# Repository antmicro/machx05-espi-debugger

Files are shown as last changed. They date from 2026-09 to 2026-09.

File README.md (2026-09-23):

# MachXO5 eSPI Debugger

Copyright (c) 2026 [Antmicro](https://www.antmicro.com)

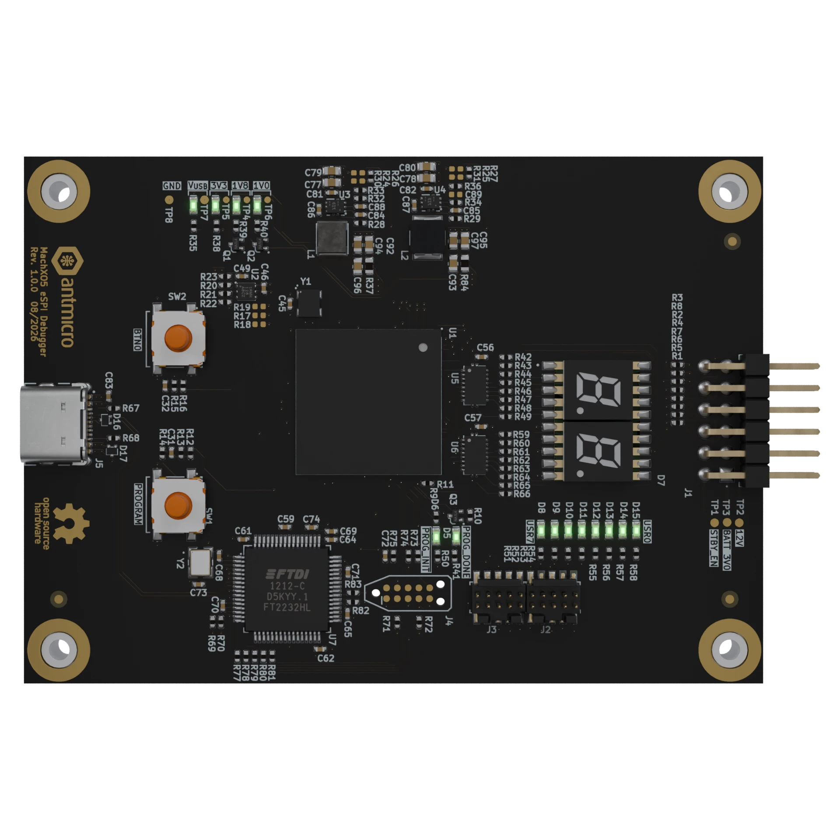
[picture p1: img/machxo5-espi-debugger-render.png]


## Overview

This project contains open hardware design files for an FPGA-based debug board built around the Lattice MachXO5-NX FPGA.
The board is designed to aid the process of development, bring-up and integration of eSPI-based connections to Data Center Secure Control Modules (DC-SCMs).
It provides USB-accessible UART and JTAG interfaces and a Port 80 status display, enabling development, testing and debugging of eSPI communication before integration into a target server platform.
This project includes only PCB design files - as dedicated bitstream needs to be generated for the on-board Lattice FPGA in order to make it work.
The PCB design files were prepared in KiCad 10.x.

## Key features

* Lattice [MachXO5-NX LFMXO5-25-7BBG400C](https://www.latticesemi.com/en/Products/FPGAandCPLD/MachXO5-NX) FPGA
* Generic 0.1 inch pinhead connector for interfacing with HPM subsystem
* USB-C port with FTDI FT2232H USB interface bridge
* UART and JTAG interfaces accessible from the USB interface bridge
* Port 80 status display with LED indicators
* 125 MHz on-board clock source
* 62 x 87 mm (2.44 x 3.42 inch) PCB outline

## Project structure

The main directory contains KiCad PCB project files, the LICENSE, and this README, and the img directory contains graphics for this README.

## License

This project is licensed under the [Apache-2.0](LICENSE) license.

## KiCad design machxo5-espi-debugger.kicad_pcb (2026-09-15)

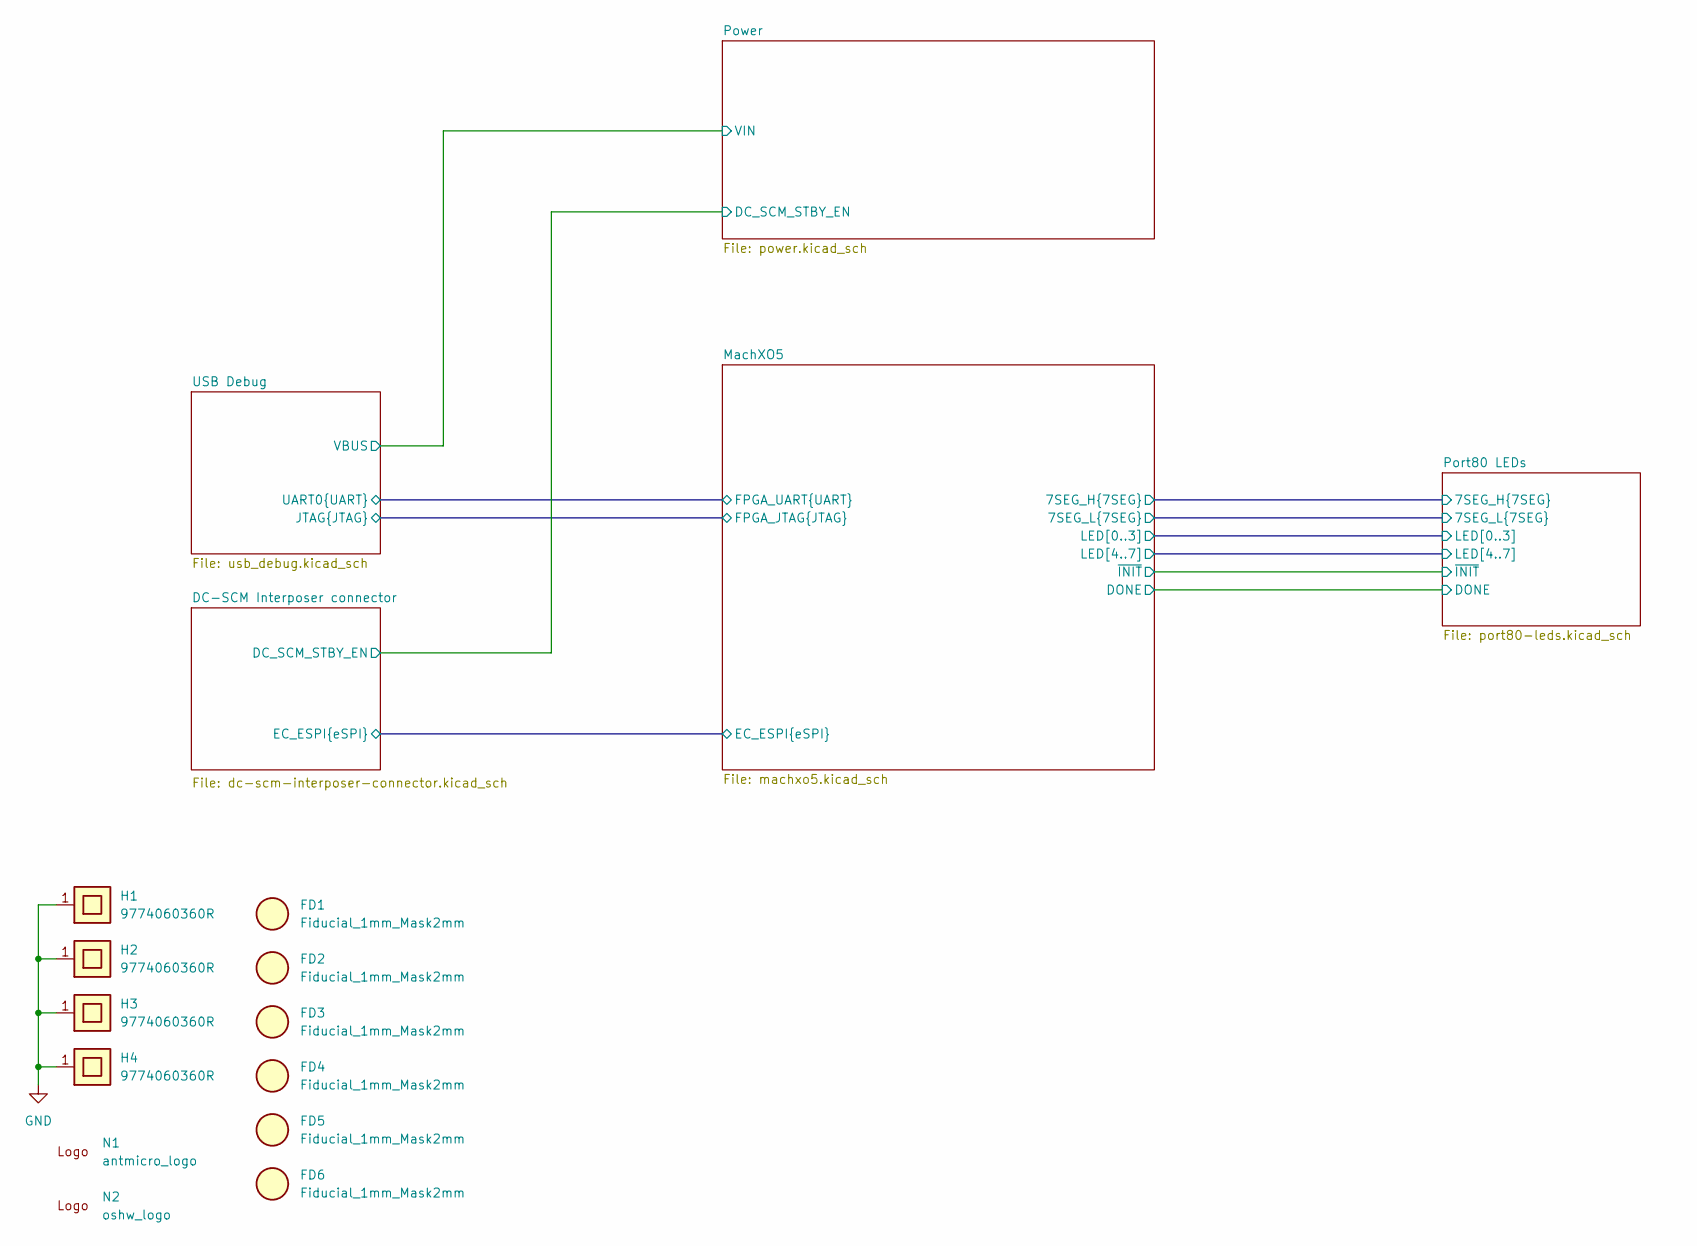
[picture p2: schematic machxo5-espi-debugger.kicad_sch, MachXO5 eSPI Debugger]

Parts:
FD1, FD2, FD3, FD4, FD5, FD6: Fiducial_1mm_Mask2mm
H1, H2, H3, H4: Spacer_Drill4.4mm_H6mm_9774060360R; MPN 9774060360R
N1: antmicro_logo; antmicro-logo_scaled_12mm
N2: oshw_logo; oshw-logo

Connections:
GND: H1.1, H2.1, H3.1, H4.1; also elsewhere on the board

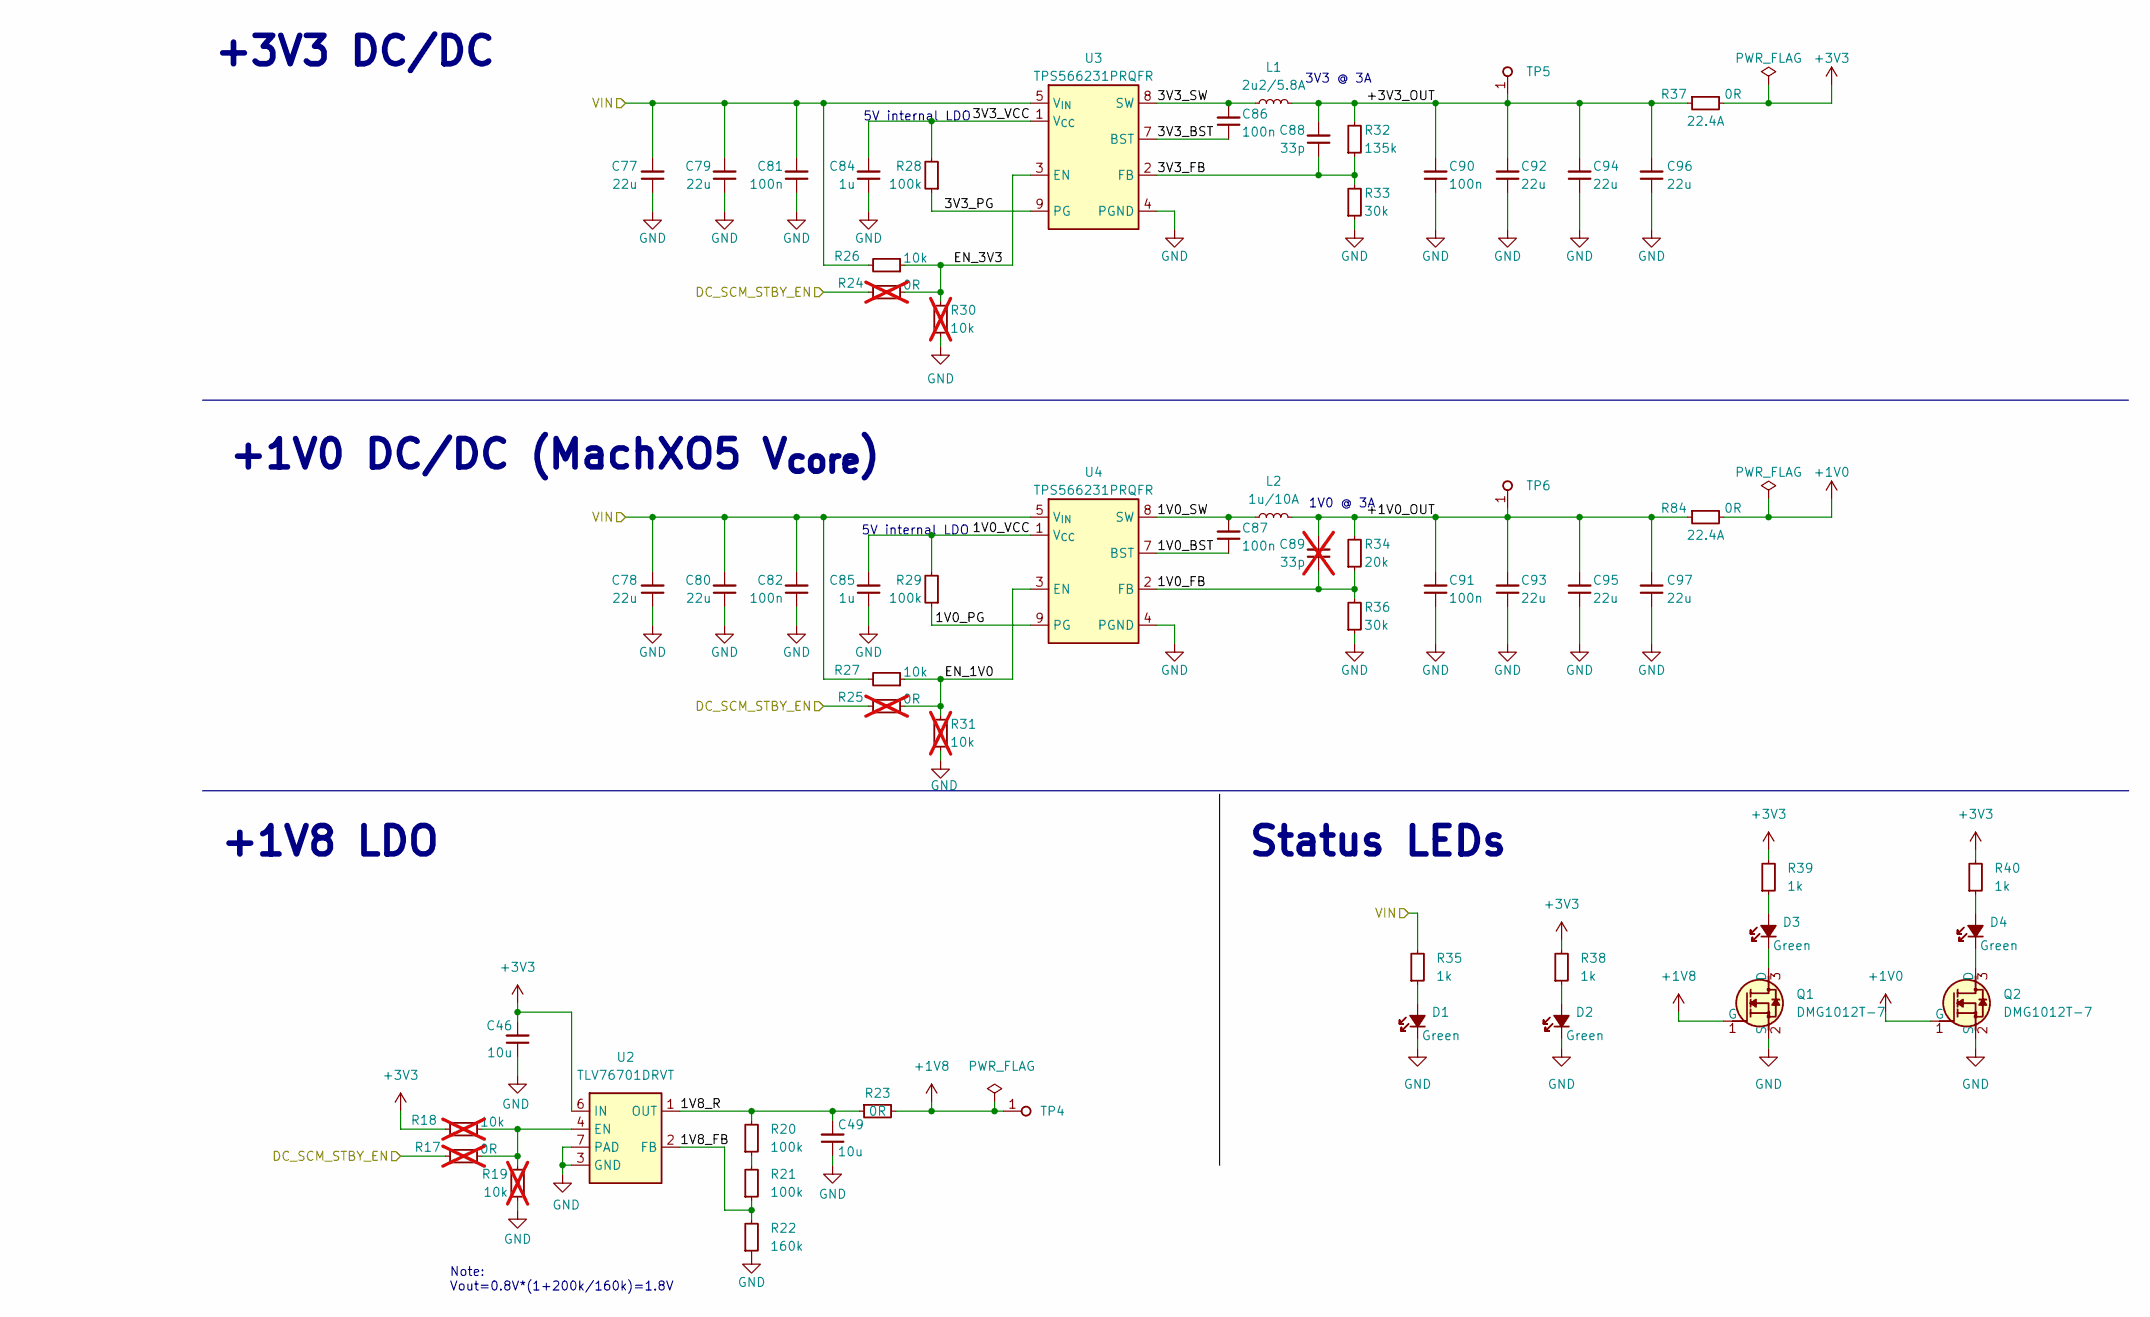
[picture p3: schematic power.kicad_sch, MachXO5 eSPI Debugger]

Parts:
C46, C49: C_10u_10V_0402; C_0402_1005Metric; Voltage 10V; MPN GRM155R61A106ME11D
C77, C78, C79, C80, C92, C93, C94, C95, C96, C97: C_22u_16V_0603; C_0603_1608Metric_EIA; Voltage 16V; MPN CL10A226MO7JZNC
C81, C82, C86, C87, C90, C91: C_100n_0402; C_0402_1005Metric; Voltage 50V; MPN GRM155R61H104KE14D
C84, C85: C_1u_25V_0402; C_0402_1005Metric; Voltage 25V; MPN GRM155R61E105KE11J
C88: C_33p_0402; C_0402_1005Metric; MPN 04025A330FAT2A
C89: C_33p_0402; C_0402_1005Metric; MPN 04025A330FAT2A; not fitted
D1, D2, D3, D4: LED_G_0603_LTST-C190GKT; LED_0603_1608Metric_G; MPN LTST-C190GKT
L1: L_2u2_5.8A_WE-PMFI-35329222; L_WE-PMFI-353220; MPN 74479335329222
L2: L_1u_10A_Bourns-SRP4021HMT; L_Bourns-SRP4021HMT; MPN SRP4021HMT-1R0M
Q1, Q2: DMG1012T-7; SOT-523; MPN DMG1012T-7
R17, R24, R25: R_0R_0402; R_0402_1005Metric; MPN ERJ2GE0R00X; not fitted
R18, R19, R30, R31: R_10k_0402; R_0402_1005Metric; Tolerance 1%; MPN CR0402-FX-1002GLF; not fitted
R20, R21, R28, R29: R_100k_0402; R_0402_1005Metric; Tolerance 1%; MPN CR0402-FX-1003GLF
R22: R_160k_0402; R_0402_1005Metric; Tolerance 1%; MPN CR0402-FX-1603GLF
R23: R_0R_0402; R_0402_1005Metric; MPN ERJ2GE0R00X
R26, R27: R_10k_0402; R_0402_1005Metric; Tolerance 1%; MPN CR0402-FX-1002GLF
R32: R_135k_0402; R_0402_1005Metric; Tolerance 0.1%; MPN RT0805BRD07135KL
R33, R36: R_30k_0402; R_0402_1005Metric; Tolerance 1%; MPN CR0402-FX-3002GLF
R34: R_20k_0402; R_0402_1005Metric; Tolerance 1%; MPN CR0402-FX-2002GLF
R35, R38, R39, R40: R_1k_0402; R_0402_1005Metric; Tolerance 1%; MPN CR0402-FX-1001GLF
R37, R84: R_0R_22.4A_0603; R_0603_1608Metric; Tolerance template_tolerance; MPN PMR03EZPJ000
TP4, TP5, TP6: TP_0.75mm_SMD; TP_SMD_0.75mm
U2: TLV76701_WSON; WSON-6-1EP_2x2mm_P0.65mm; MPN TLV76701DRVT
U3, U4: TPS566231P; VQFN-HR-9_2x1.5mm; MPN TPS566231PRQFR

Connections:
+1V0: Q2.1 (G), R84.2; also elsewhere on the board
+1V8: Q1.1 (G), R23.2, TP4.1 (1_1); also elsewhere on the board
+3V3: C46.2, R18.2, R37.2, R38.2, R39.2, R40.2, U2.6 (IN); also elsewhere on the board
/DC-SCM Interposer connector/DC_SCM_STBY_EN: R17.1, R24.1, R25.1; also elsewhere on the board
/Power/1V0_BST: C87.1, U4.7 (BST)
/Power/1V0_FB: C89.1, R34.1, R36.2, U4.2 (FB)
/Power/1V0_PG: R29.1, U4.9 (PG)
/Power/1V0_SW: C87.2, L2.1, U4.8 (SW)
/Power/1V0_VCC: C85.2, R29.2, U4.1 (V_{CC})
/Power/1V8_FB: R21.1, R22.2, U2.2 (FB)
/Power/1V8_R: C49.2, R20.2, R23.1, U2.1 (OUT)
/Power/3V3_BST: C86.1, U3.7 (BST)
/Power/3V3_FB: C88.1, R32.1, R33.2, U3.2 (FB)
/Power/3V3_PG: R28.1, U3.9 (PG)
/Power/3V3_SW: C86.2, L1.1, U3.8 (SW)
/Power/3V3_VCC: C84.2, R28.2, U3.1 (V_{CC})
/Power/+1V0_OUT: C89.2, C91.2, C93.2, C95.2, C97.2, L2.2, R34.2, R84.1, TP6.1 (1_1)
/Power/+3V3_OUT: C88.2, C90.2, C92.2, C94.2, C96.2, L1.2, R32.2, R37.1, TP5.1 (1_1)
/Power/EN_1V0: R25.2, R27.1, R31.2, U4.3 (EN)
/Power/EN_3V3: R24.2, R26.1, R30.2, U3.3 (EN)
/Power/VIN: C77.2, C78.2, C79.2, C80.2, C81.2, C82.2, R26.2, R27.2, R35.2, U3.5 (V_{IN}), U3.6 (V_{IN}), U4.5 (V_{IN}), U4.6 (V_{IN}); also elsewhere on the board
GND: C46.1, C49.1, C77.1, C78.1, C79.1, C80.1, C81.1, C82.1, C84.1, C85.1, C90.1, C91.1, C92.1, C93.1, C94.1, C95.1, C96.1, C97.1, D1.1 (C), D2.1 (C), Q1.2 (S), Q2.2 (S), R19.1, R22.1, R30.1, R31.1, R33.1, R36.1, U2.3 (GND), U2.5 (GND), U2.7 (PAD), U3.4 (PGND), U4.4 (PGND); also elsewhere on the board
unnamed: D1.2 (A), R35.1
unnamed: D2.2 (A), R38.1
unnamed: D3.2 (A), R39.1
unnamed: D3.1 (C), Q1.3 (D)
unnamed: D4.2 (A), R40.1
unnamed: D4.1 (C), Q2.3 (D)
unnamed: R20.1, R21.2
unnamed: R17.2, R18.1, R19.2, U2.4 (EN)

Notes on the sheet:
5V internal LDO
Note: Vout=0.8V*(1+200k/160k)=1.8V
3V3 @ 3A
Status LEDs
+1V8 LDO
1V0 @ 3A
+1V0 DC/DC (MachXO5 V_{core})
+3V3 DC/DC

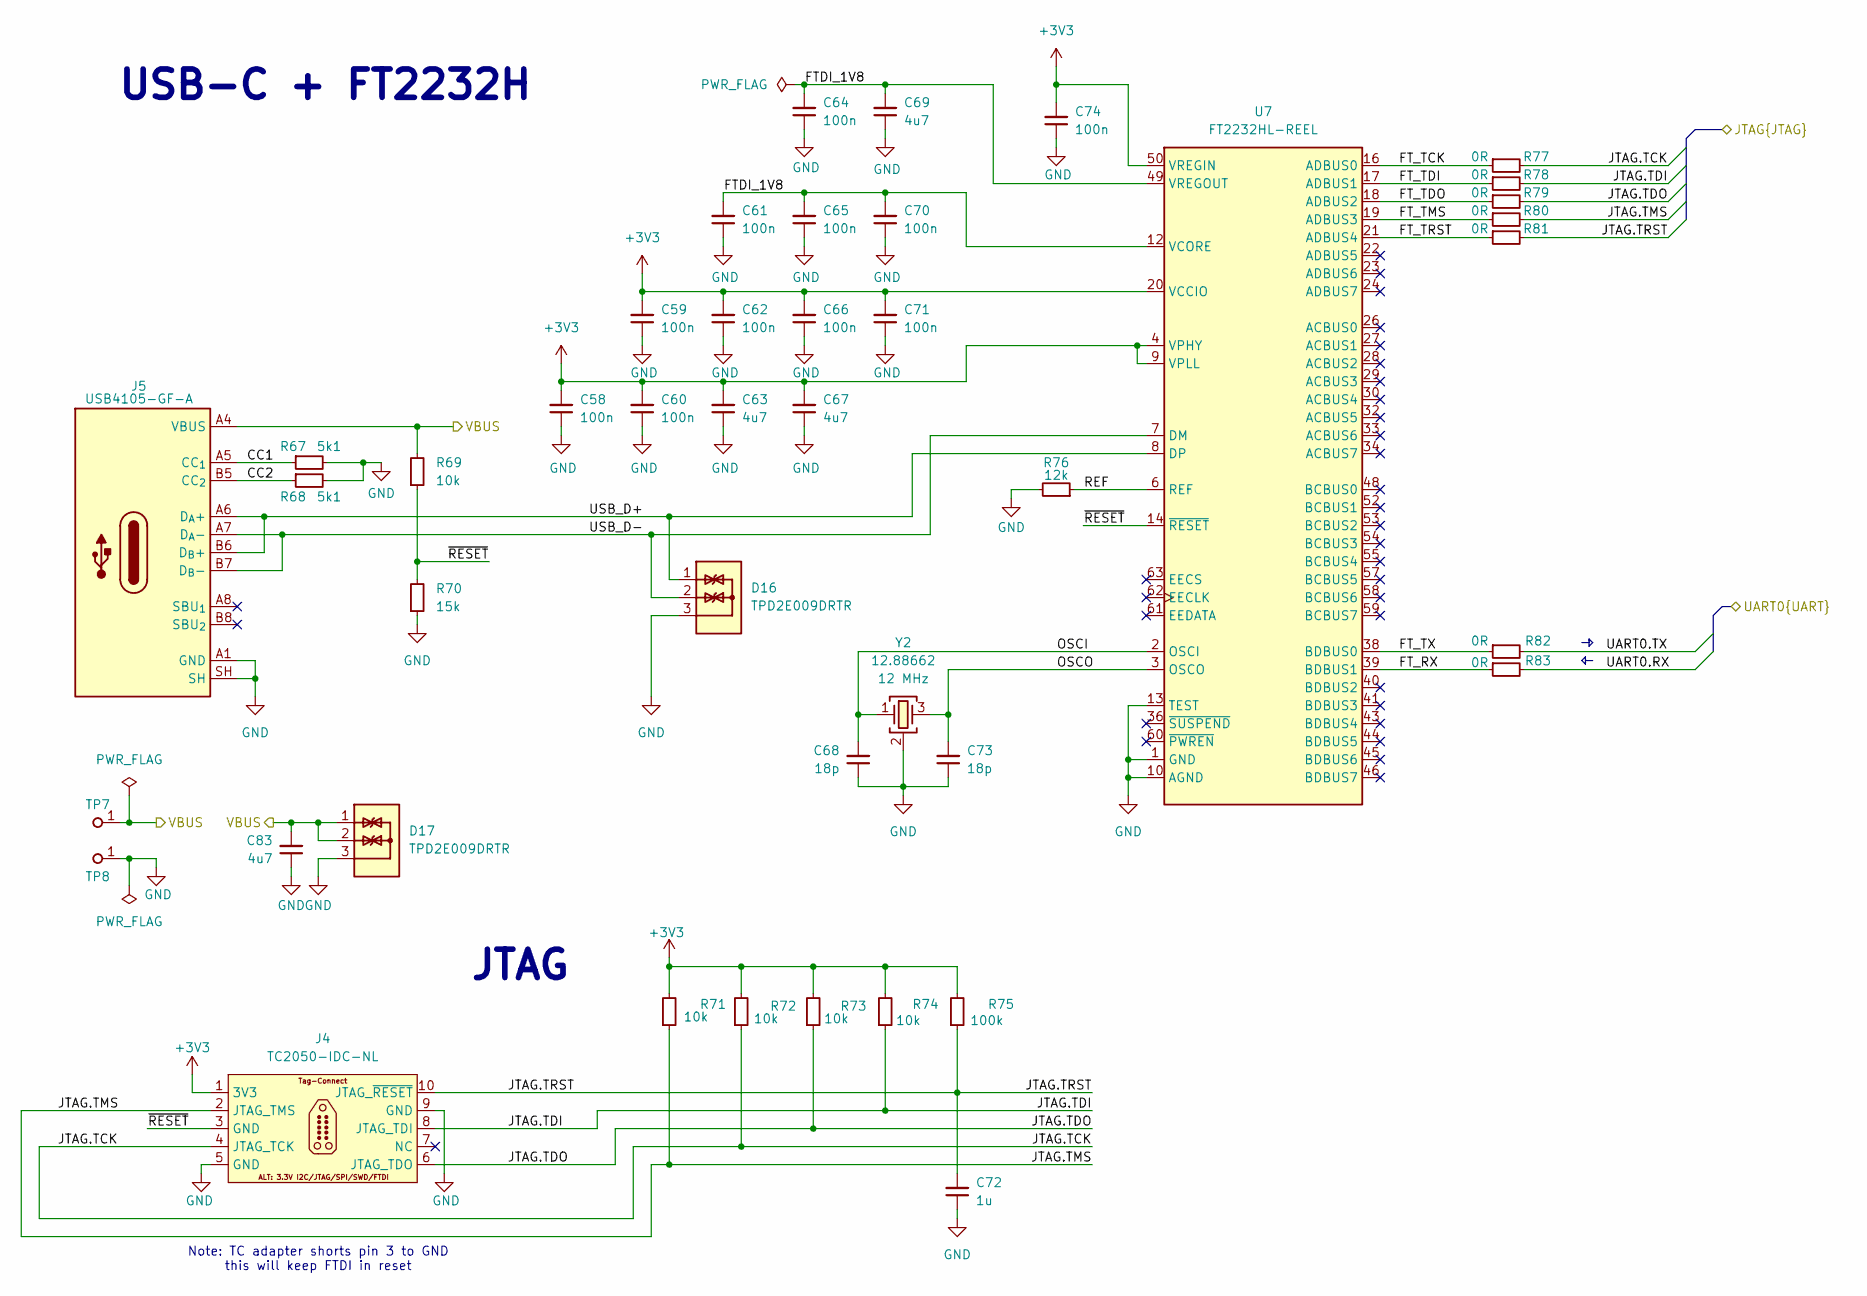
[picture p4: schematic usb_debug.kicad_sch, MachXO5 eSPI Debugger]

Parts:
C58, C59, C60, C61, C62, C64, C65, C66, C70, C71, C74: C_100n_16V_X7R_0402; C_0402_1005Metric; Voltage 16V; MPN C0402C104J4RAC7411
C63, C67, C69, C83: C_4u7_10V_X7T_0402; C_0402_1005Metric; Voltage 10V; MPN GRM155D71A475ME15D
C68, C73: C_18p_0402; C_0402_1005Metric; MPN CL05C180JB51PNC
C72: C_1u_0402; C_0402_1005Metric; MPN C1005X6S1A105K050BC
D16, D17: TPD2E009_SOT-9X3; SOT-723; MPN TPD2E009DRTR
J4: Tag-Connect_TC2050-IDC-NL_2x5_P1.27mm; MPN TC2050-IDC-NL
J5: USB-C_GCT_USB4105-GF-A; USB-C_Receptacle_GCT_USB4105-GF-A; MPN USB4105-GF-A
R67, R68: R_5k1_0402; R_0402_1005Metric; Tolerance 1%; MPN CR0402-FX-5101GLF
R69, R71, R72, R73, R74: R_10k_0402; R_0402_1005Metric; Tolerance 1%; MPN CR0402-FX-1002GLF
R70: R_15k_0402; R_0402_1005Metric; Tolerance 1%; MPN CR0402-FX-1502GLF
R75: R_100k_0402; R_0402_1005Metric; Tolerance 1%; MPN CR0402-FX-1003GLF
R76: R_12k_0402; R_0402_1005Metric; Tolerance 1%; MPN CR0402-FX-1202GLF
R77, R78, R79, R80, R81, R82, R83: R_0R_0402; R_0402_1005Metric; MPN ERJ2GE0R00X
TP7, TP8: TP_1mm_SMD; TP_SMD_1mm
U7: FT2232HL-REEL; LQFP-64_10x10mm_P0.5mm; MPN FT2232HL-REEL
Y2: Resonator_12MHz_KX-7; Resonator_SMD_Geyer_KX-7_3.2x2.5x0.8mm; MPN 12.88662

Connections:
+3V3: C58.2, C59.2, C60.2, C62.2, C63.2, C66.2, C67.2, C71.2, C74.2, J4.1, R71.2, R72.2, R73.2, R74.2, R75.2, U7.4 (VPHY), U7.9 (VPLL), U7.20 (VCCIO), U7.31 (VCCIO), U7.42 (VCCIO), U7.50 (VREGIN), U7.56 (VCCIO); also elsewhere on the board
/MachXO5/FPGA_JTAG.TCK: J4.4, R72.1, R77.2; also elsewhere on the board
/MachXO5/FPGA_JTAG.TDI: J4.8, R74.1, R78.2; also elsewhere on the board
/MachXO5/FPGA_JTAG.TDO: J4.6, R73.1, R79.2; also elsewhere on the board
/MachXO5/FPGA_JTAG.TMS: J4.2, R71.1, R80.2; also elsewhere on the board
/MachXO5/FPGA_JTAG.TRST: C72.2, J4.10, R75.1, R81.2; also elsewhere on the board
/MachXO5/FPGA_UART.RX: R83.2; also elsewhere on the board
/MachXO5/FPGA_UART.TX: R82.2; also elsewhere on the board
/Power/VIN: C83.2, D17.1, D17.2, J5.A4 (VBUS), J5.A9 (VBUS), J5.B4 (VBUS), J5.B9 (VBUS), R69.2, TP7.1 (1_1); also elsewhere on the board
/USB Debug/CC1: J5.A5 (CC_{1}), R67.1
/USB Debug/CC2: J5.B5 (CC_{2}), R68.1
/USB Debug/FTDI_1V8: C61.2, C64.2, C65.2, C69.2, C70.2, U7.12 (VCORE), U7.37 (VCORE), U7.49 (VREGOUT), U7.64 (VCORE)
/USB Debug/FT_RX: R83.1, U7.39 (BDBUS1)
/USB Debug/FT_TCK: R77.1, U7.16 (ADBUS0)
/USB Debug/FT_TDI: R78.1, U7.17 (ADBUS1)
/USB Debug/FT_TDO: R79.1, U7.18 (ADBUS2)
/USB Debug/FT_TMS: R80.1, U7.19 (ADBUS3)
/USB Debug/FT_TRST: R81.1, U7.21 (ADBUS4)
/USB Debug/FT_TX: R82.1, U7.38 (BDBUS0)
/USB Debug/OSCI: C68.2, U7.2 (OSCI), Y2.1
/USB Debug/OSCO: C73.2, U7.3 (OSCO), Y2.3
/USB Debug/REF: R76.1, U7.6 (REF)
/USB Debug/USB_D+: D16.1, J5.A6 (D_{A}+), J5.B6 (D_{B}+), U7.8 (DP)
/USB Debug/USB_D-: D16.2, J5.A7 (D_{A}-), J5.B7 (D_{B}-), U7.7 (DM)
/USB Debug/~RESET: J4.3, R69.1, R70.2, U7.14 (~RESET)
GND: C58.1, C59.1, C60.1, C61.1, C62.1, C63.1, C64.1, C65.1, C66.1, C67.1, C68.1, C69.1, C70.1, C71.1, C72.1, C73.1, C74.1, C83.1, D16.3, D17.3, J4.5, J4.9, J5.A1 (GND), J5.A12 (GND), J5.B1 (GND), J5.B12 (GND), J5.SH, R67.2, R68.2, R70.1, R76.2, TP8.1 (1_1), U7.1 (GND), U7.5 (GND), U7.10 (AGND), U7.11 (GND), U7.13 (TEST), U7.15 (GND), U7.25 (GND), U7.35 (GND), U7.47 (GND), U7.51 (GND), Y2.2 (SH), Y2.4 (SH); also elsewhere on the board

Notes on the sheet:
JTAG
USB-C + FT2232H
Note: TC adapter shorts pin 3 to GND this will keep FTDI in reset

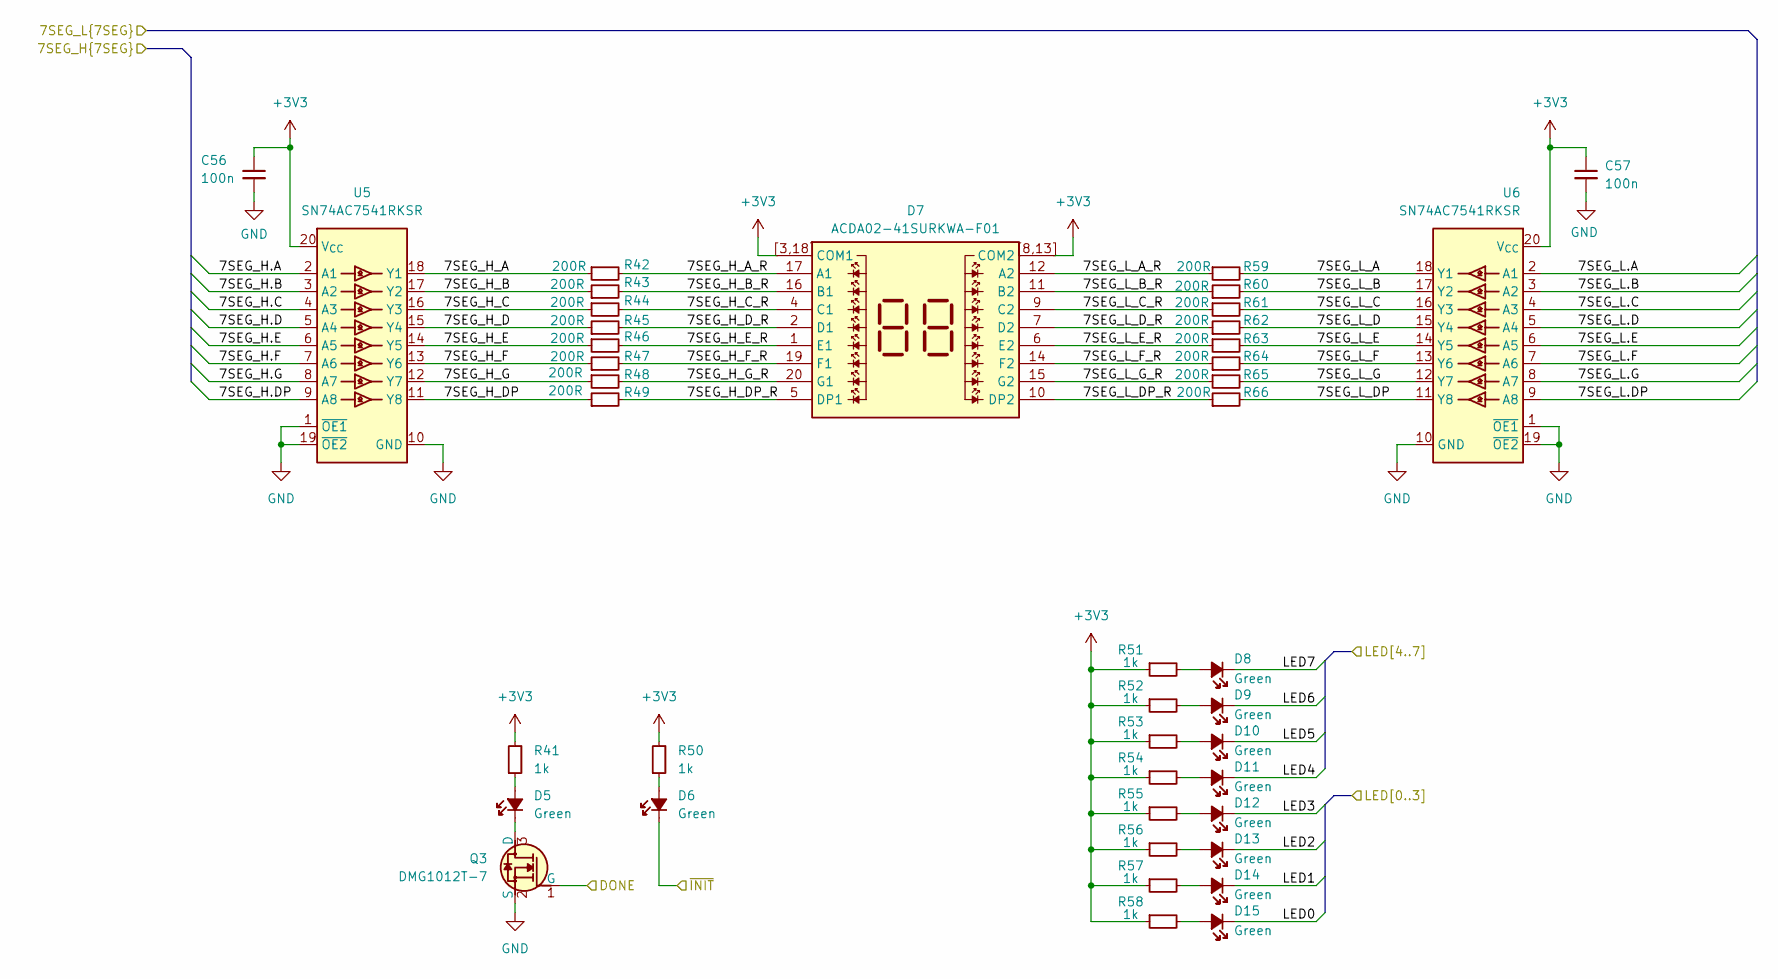
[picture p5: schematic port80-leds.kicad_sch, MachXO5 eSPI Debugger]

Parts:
C56, C57: C_100n_0402; C_0402_1005Metric; Voltage 50V; MPN GRM155R61H104KE14D
D5, D6, D8, D9, D10, D11, D12, D13, D14, D15: LED_G_0603_LTST-C190GKT; LED_0603_1608Metric_G; MPN LTST-C190GKT
D7: ACDA02-41SURKWA-F01; MPN ACDA02-41SURKWA-F01
Q3: DMG1012T-7; SOT-523; MPN DMG1012T-7
R41, R50, R51, R52, R53, R54, R55, R56, R57, R58: R_1k_0402; R_0402_1005Metric; Tolerance 1%; MPN CR0402-FX-1001GLF
R42, R43, R44, R45, R46, R47, R48, R49, R59, R60, R61, R62, R63, R64, R65, R66: R_200R_0402; R_0402_1005Metric; Tolerance 1%; MPN CR0402-FX-2000GLF
U5, U6: SN74AC7541_VQFN; VQFN-20_1EP_4.5x2.5mm_P0.5mm; MPN SN74AC7541RKSR

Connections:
+3V3: C56.1, C57.1, D7.3 (COM1), D7.8 (COM2), D7.13 (COM2), D7.18 (COM1), D7.[3,18] (COM1), D7.[8,13] (COM2), R41.2, R50.2, R51.1, R52.1, R53.1, R54.1, R55.1, R56.1, R57.1, R58.1, U5.20 (V_{CC}), U6.20 (V_{CC}); also elsewhere on the board
/MachXO5/7SEG_H.A: U5.2 (A1); also elsewhere on the board
/MachXO5/7SEG_H.B: U5.3 (A2); also elsewhere on the board
/MachXO5/7SEG_H.C: U5.4 (A3); also elsewhere on the board
/MachXO5/7SEG_H.D: U5.5 (A4); also elsewhere on the board
/MachXO5/7SEG_H.DP: U5.9 (A8); also elsewhere on the board
/MachXO5/7SEG_H.E: U5.6 (A5); also elsewhere on the board
/MachXO5/7SEG_H.F: U5.7 (A6); also elsewhere on the board
/MachXO5/7SEG_H.G: U5.8 (A7); also elsewhere on the board
/MachXO5/7SEG_L.A: U6.2 (A1); also elsewhere on the board
/MachXO5/7SEG_L.B: U6.3 (A2); also elsewhere on the board
/MachXO5/7SEG_L.C: U6.4 (A3); also elsewhere on the board
/MachXO5/7SEG_L.D: U6.5 (A4); also elsewhere on the board
/MachXO5/7SEG_L.DP: U6.9 (A8); also elsewhere on the board
/MachXO5/7SEG_L.E: U6.6 (A5); also elsewhere on the board
/MachXO5/7SEG_L.F: U6.7 (A6); also elsewhere on the board
/MachXO5/7SEG_L.G: U6.8 (A7); also elsewhere on the board
/MachXO5/DONE: Q3.1 (G); also elsewhere on the board
/MachXO5/LED0: D15.1 (C); also elsewhere on the board
/MachXO5/LED1: D14.1 (C); also elsewhere on the board
/MachXO5/LED2: D13.1 (C); also elsewhere on the board
/MachXO5/LED3: D12.1 (C); also elsewhere on the board
/MachXO5/LED4: D11.1 (C); also elsewhere on the board
/MachXO5/LED5: D10.1 (C); also elsewhere on the board
/MachXO5/LED6: D9.1 (C); also elsewhere on the board
/MachXO5/LED7: D8.1 (C); also elsewhere on the board
/MachXO5/~INIT: D6.1 (C); also elsewhere on the board
/Port80 LEDs/7SEG_H_A: R42.1, U5.18 (Y1)
/Port80 LEDs/7SEG_H_A_R: D7.17 (A1), R42.2
/Port80 LEDs/7SEG_H_B: R43.1, U5.17 (Y2)
/Port80 LEDs/7SEG_H_B_R: D7.16 (B1), R43.2
/Port80 LEDs/7SEG_H_C: R44.1, U5.16 (Y3)
/Port80 LEDs/7SEG_H_C_R: D7.4 (C1), R44.2
/Port80 LEDs/7SEG_H_D: R45.1, U5.15 (Y4)
/Port80 LEDs/7SEG_H_DP: R49.1, U5.11 (Y8)
/Port80 LEDs/7SEG_H_DP_R: D7.5 (DP1), R49.2
/Port80 LEDs/7SEG_H_D_R: D7.2 (D1), R45.2
/Port80 LEDs/7SEG_H_E: R46.1, U5.14 (Y5)
/Port80 LEDs/7SEG_H_E_R: D7.1 (E1), R46.2
/Port80 LEDs/7SEG_H_F: R47.1, U5.13 (Y6)
/Port80 LEDs/7SEG_H_F_R: D7.19 (F1), R47.2
/Port80 LEDs/7SEG_H_G: R48.1, U5.12 (Y7)
/Port80 LEDs/7SEG_H_G_R: D7.20 (G1), R48.2
/Port80 LEDs/7SEG_L_A: R59.2, U6.18 (Y1)
/Port80 LEDs/7SEG_L_A_R: D7.12 (A2), R59.1
/Port80 LEDs/7SEG_L_B: R60.2, U6.17 (Y2)
/Port80 LEDs/7SEG_L_B_R: D7.11 (B2), R60.1
/Port80 LEDs/7SEG_L_C: R61.2, U6.16 (Y3)
/Port80 LEDs/7SEG_L_C_R: D7.9 (C2), R61.1
/Port80 LEDs/7SEG_L_D: R62.2, U6.15 (Y4)
/Port80 LEDs/7SEG_L_DP: R66.2, U6.11 (Y8)
/Port80 LEDs/7SEG_L_DP_R: D7.10 (DP2), R66.1
/Port80 LEDs/7SEG_L_D_R: D7.7 (D2), R62.1
/Port80 LEDs/7SEG_L_E: R63.2, U6.14 (Y5)
/Port80 LEDs/7SEG_L_E_R: D7.6 (E2), R63.1
/Port80 LEDs/7SEG_L_F: R64.2, U6.13 (Y6)
/Port80 LEDs/7SEG_L_F_R: D7.14 (F2), R64.1
/Port80 LEDs/7SEG_L_G: R65.2, U6.12 (Y7)
/Port80 LEDs/7SEG_L_G_R: D7.15 (G2), R65.1
GND: C56.2, C57.2, Q3.2 (S), U5.1 (~OE1), U5.10 (GND), U5.19 (~OE2), U5.21 (GND), U6.1 (~OE1), U6.10 (GND), U6.19 (~OE2), U6.21 (GND); also elsewhere on the board
unnamed: D5.2 (A), R41.1
unnamed: D5.1 (C), Q3.3 (D)
unnamed: D6.2 (A), R50.1
unnamed: D8.2 (A), R51.2
unnamed: D9.2 (A), R52.2
unnamed: D10.2 (A), R53.2
unnamed: D11.2 (A), R54.2
unnamed: D12.2 (A), R55.2
unnamed: D13.2 (A), R56.2
unnamed: D14.2 (A), R57.2
unnamed: D15.2 (A), R58.2

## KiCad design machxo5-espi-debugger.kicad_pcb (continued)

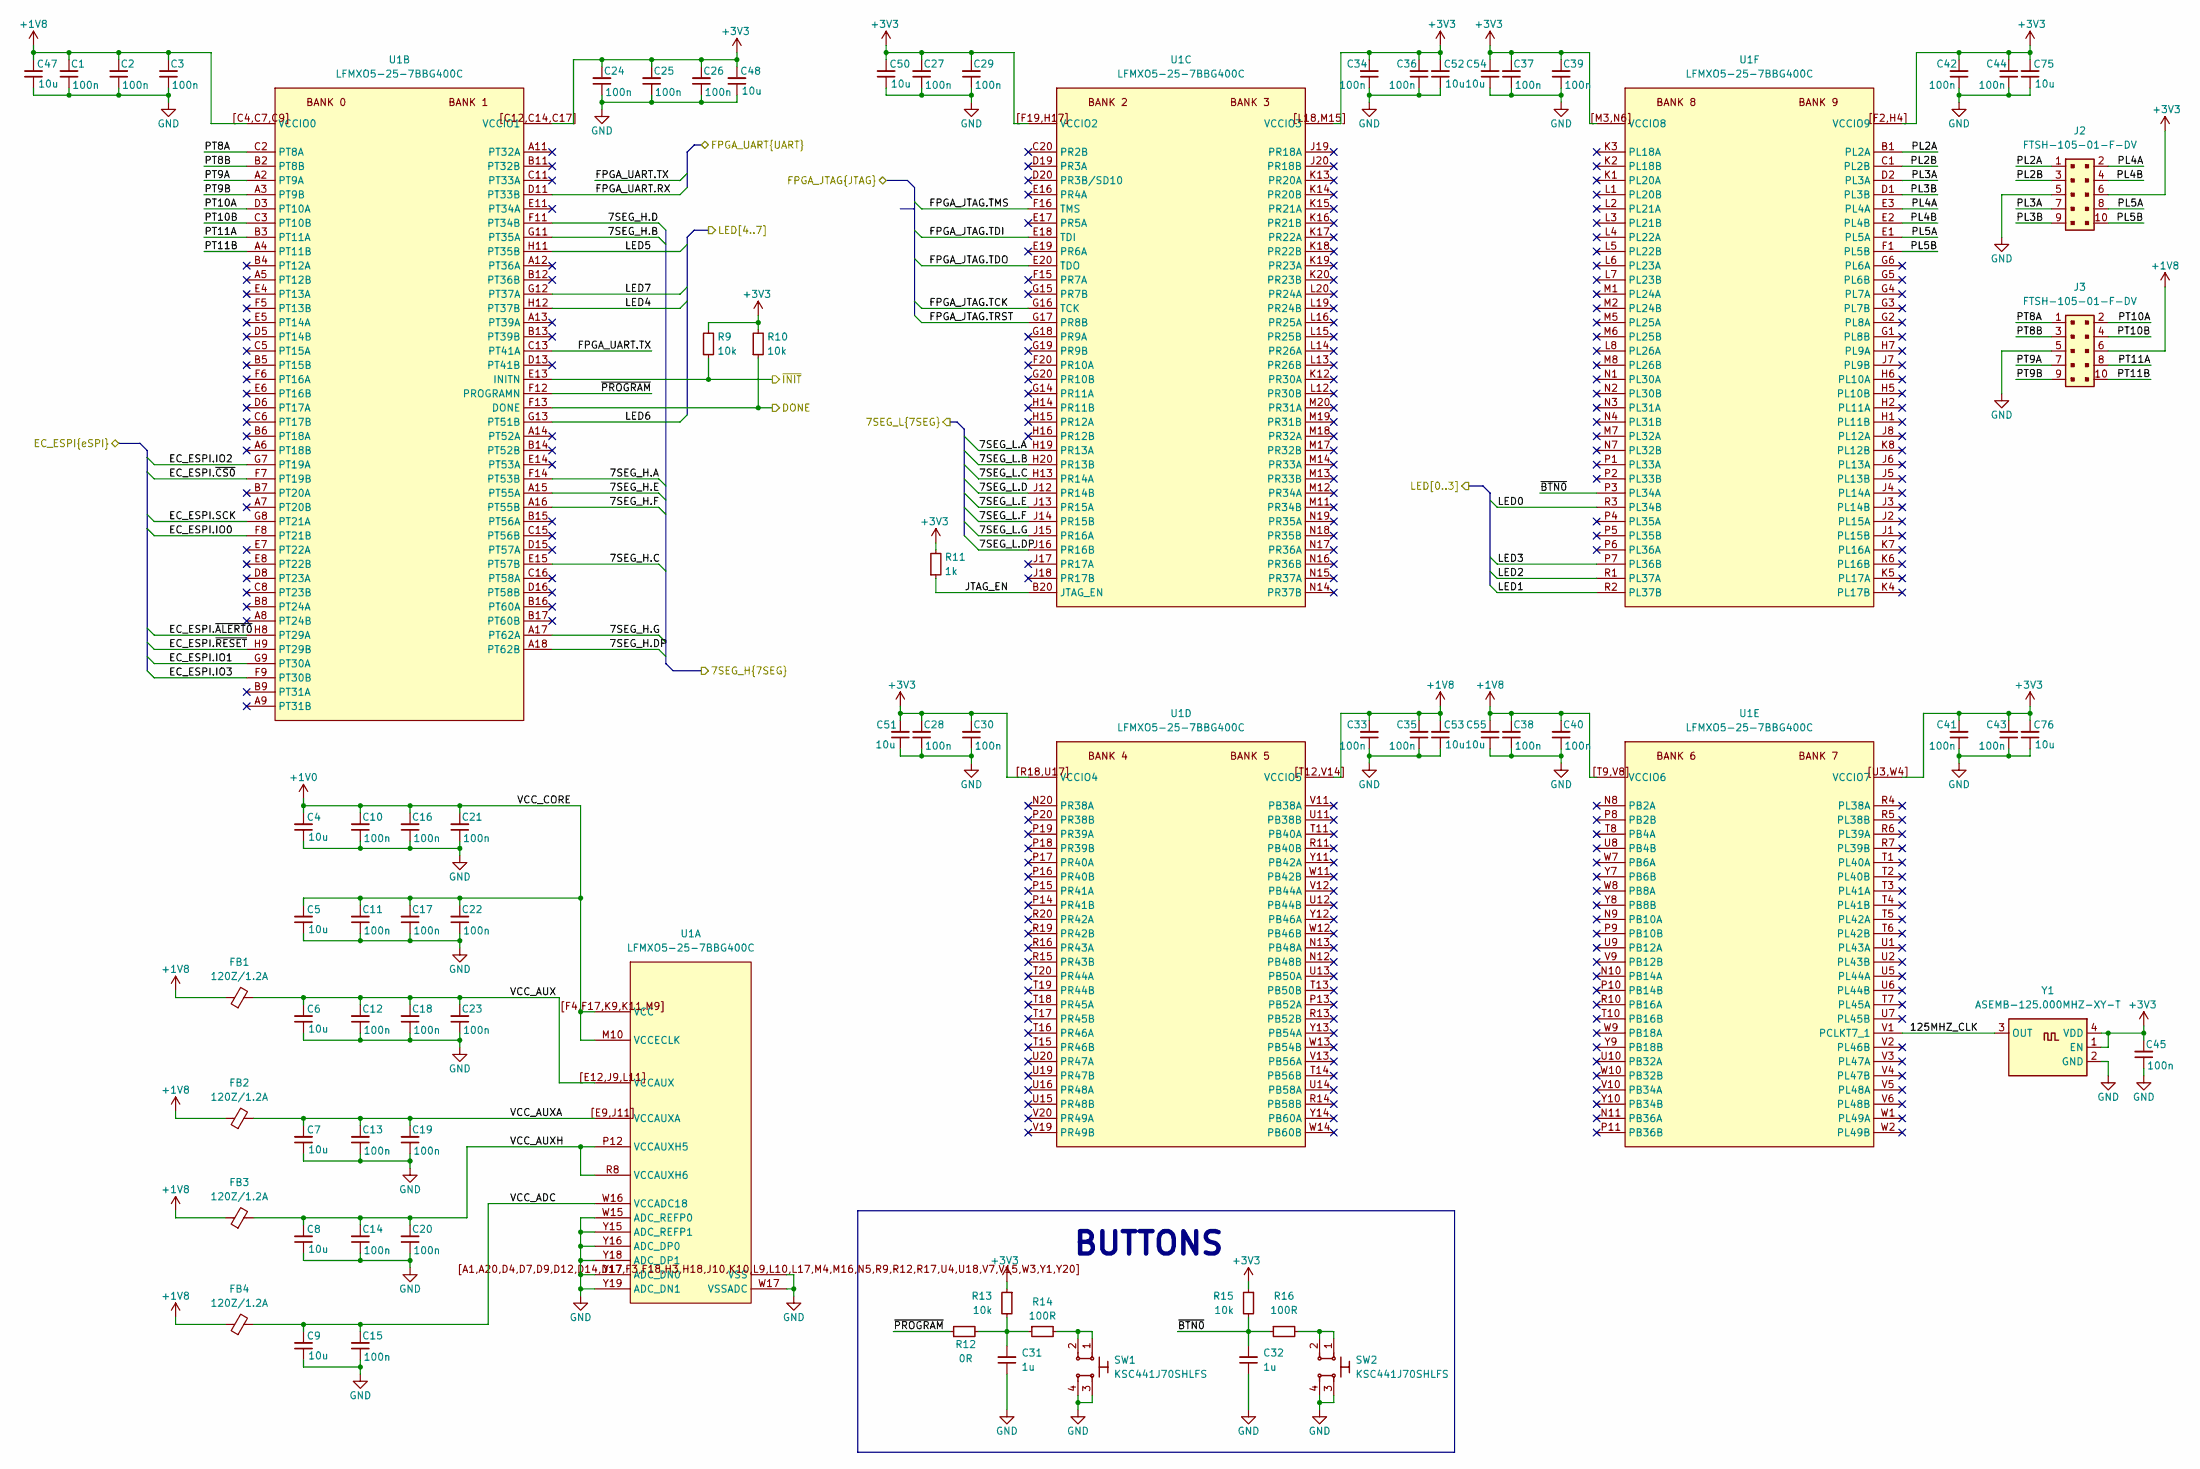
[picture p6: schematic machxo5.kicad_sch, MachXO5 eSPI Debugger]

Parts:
C1, C2, C3, C10, C11, C12, C13, C14, C15, C16, C17, C18, C19, C20, C21, C22, C23, C24, C25, C26, C27, C28, C29, C30, C33, C34, C35, C36, C37, C38, C39, C40, C41, C42, C43, C44, C45: C_100n_0402; C_0402_1005Metric; Voltage 50V; MPN GRM155R61H104KE14D
C4, C5, C6, C7, C8, C9, C47, C48, C50, C51, C52, C53, C54, C55, C75, C76: C_10u_6.3V_0402; C_0402_1005Metric; Voltage 6.3V; MPN GRM155R60J106ME15D
C31, C32: C_1u_6.3V_X6S_0402; C_0402_1005Metric; Voltage 6.3V; MPN GRT155C80J105KE01D
FB1, FB2, FB3, FB4: FB_120Z_1.2A_TDK-MPZ_0402; FB_0402_1005Metric; MPN MPZ1005S121CT000
J2, J3: PinHeader_2x5_P1.27mm_SMD; MPN FTSH-105-01-F-DV
R9, R10, R13, R15: R_10k_0402; R_0402_1005Metric; Tolerance 1%; MPN CR0402-FX-1002GLF
R11: R_1k_0402; R_0402_1005Metric; Tolerance 1%; MPN CR0402-FX-1001GLF
R12: R_0R_0402; R_0402_1005Metric; MPN ERJ2GE0R00X
R14, R16: R_100R_0402; R_0402_1005Metric; Tolerance 1%; MPN CR0402-FX-1000GLF
SW1, SW2: SW_KSC441J70SHLFS_SMD; MPN KSC441J70SHLFS
U1: LFMXO5-25-7BBG400C; BGA-400-17x17x0.8mm_Layout20x20_P0.8mm; MPN LFMXO5-25-7BBG400C
Y1: Oscillator_125MHz_ASEMB; Oscillator_SMD_Abracon_ASEMB_3.2x2.5mm; MPN ASEMB-125.000MHZ-XY-T

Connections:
+1V0: C4.2, C5.2, C10.2, C11.2, C16.2, C17.2, C21.2, C22.2, U1.F4 (VCC), U1.F17 (VCC), U1.K9 (VCC), U1.K11 (VCC), U1.M9 (VCC), U1.M10 (VCCECLK), U1.[F4,F17,K9,K11,M9] (VCC); also elsewhere on the board
+1V8: C1.2, C2.2, C3.2, C33.2, C35.2, C38.2, C40.2, C47.2, C53.2, C55.2, FB1.1, FB2.1, FB3.1, FB4.1, J3.6, U1.C4 (VCCIO0), U1.C7 (VCCIO0), U1.C9 (VCCIO0), U1.T9 (VCCIO6), U1.T12 (VCCIO5), U1.V8 (VCCIO6), U1.V14 (VCCIO5), U1.[C4,C7,C9] (VCCIO0), U1.[T9,V8] (VCCIO6), U1.[T12,V14] (VCCIO5); also elsewhere on the board
+3V3: C24.2, C25.2, C26.2, C27.2, C28.2, C29.2, C30.2, C34.2, C36.2, C37.2, C39.2, C41.2, C42.2, C43.2, C44.2, C45.2, C48.2, C50.2, C51.2, C52.2, C54.2, C75.2, C76.2, J2.6, R9.2, R10.2, R11.2, R13.1, R15.1, U1.C12 (VCCIO1), U1.C14 (VCCIO1), U1.C17 (VCCIO1), U1.F2 (VCCIO9), U1.F19 (VCCIO2), U1.H4 (VCCIO9), U1.H17 (VCCIO2), U1.L18 (VCCIO3), U1.M3 (VCCIO8), U1.M15 (VCCIO3), U1.N6 (VCCIO8), U1.R18 (VCCIO4), U1.U3 (VCCIO7), U1.U17 (VCCIO4), U1.W4 (VCCIO7), U1.[C12,C14,C17] (VCCIO1), U1.[F2,H4] (VCCIO9), U1.[F19,H17] (VCCIO2), U1.[L18,M15] (VCCIO3), U1.[M3,N6] (VCCIO8), U1.[R18,U17] (VCCIO4), U1.[U3,W4] (VCCIO7), Y1.1 (EN), Y1.4 (VDD); also elsewhere on the board
/DC-SCM Interposer connector/EC_ESPI.IO0: U1.F8 (PT21B); also elsewhere on the board
/DC-SCM Interposer connector/EC_ESPI.IO1: U1.G9 (PT30A); also elsewhere on the board
/DC-SCM Interposer connector/EC_ESPI.IO2: U1.G7 (PT19A); also elsewhere on the board
/DC-SCM Interposer connector/EC_ESPI.IO3: U1.F9 (PT30B); also elsewhere on the board
/DC-SCM Interposer connector/EC_ESPI.SCK: U1.G8 (PT21A); also elsewhere on the board
/DC-SCM Interposer connector/EC_ESPI.~ALERT0: U1.H8 (PT29A); also elsewhere on the board
/DC-SCM Interposer connector/EC_ESPI.~CS0: U1.F7 (PT19B); also elsewhere on the board
/DC-SCM Interposer connector/EC_ESPI.~RESET: U1.H9 (PT29B); also elsewhere on the board
/MachXO5/7SEG_H.A: U1.F14 (PT53B); also elsewhere on the board
/MachXO5/7SEG_H.B: U1.G11 (PT35A); also elsewhere on the board
/MachXO5/7SEG_H.C: U1.E15 (PT57B); also elsewhere on the board
/MachXO5/7SEG_H.D: U1.F11 (PT34B); also elsewhere on the board
/MachXO5/7SEG_H.DP: U1.A18 (PT62B); also elsewhere on the board
/MachXO5/7SEG_H.E: U1.A15 (PT55A); also elsewhere on the board
/MachXO5/7SEG_H.F: U1.A16 (PT55B); also elsewhere on the board
/MachXO5/7SEG_H.G: U1.A17 (PT62A); also elsewhere on the board
/MachXO5/7SEG_L.A: U1.H19 (PR13A); also elsewhere on the board
/MachXO5/7SEG_L.B: U1.H20 (PR13B); also elsewhere on the board
/MachXO5/7SEG_L.C: U1.H13 (PR14A); also elsewhere on the board
/MachXO5/7SEG_L.D: U1.J12 (PR14B); also elsewhere on the board
/MachXO5/7SEG_L.DP: U1.J16 (PR16B); also elsewhere on the board
/MachXO5/7SEG_L.E: U1.J13 (PR15A); also elsewhere on the board
/MachXO5/7SEG_L.F: U1.J14 (PR15B); also elsewhere on the board
/MachXO5/7SEG_L.G: U1.J15 (PR16A); also elsewhere on the board
/MachXO5/125MHZ_CLK: U1.V1 (PCLKT7_1), Y1.3 (OUT)
/MachXO5/DONE: R10.1, U1.F13 (DONE); also elsewhere on the board
/MachXO5/FPGA_JTAG.TCK: U1.G16 (TCK); also elsewhere on the board
/MachXO5/FPGA_JTAG.TDI: U1.E18 (TDI); also elsewhere on the board
/MachXO5/FPGA_JTAG.TDO: U1.E20 (TDO); also elsewhere on the board
/MachXO5/FPGA_JTAG.TMS: U1.F16 (TMS); also elsewhere on the board
/MachXO5/FPGA_JTAG.TRST: U1.G17 (PR8B); also elsewhere on the board
/MachXO5/FPGA_UART.RX: U1.D11 (PT33B); also elsewhere on the board
/MachXO5/FPGA_UART.TX: U1.C13 (PT41A); also elsewhere on the board
/MachXO5/JTAG_EN: R11.1, U1.B20 (JTAG_EN)
/MachXO5/LED0: U1.R3 (PL34B); also elsewhere on the board
/MachXO5/LED1: U1.R2 (PL37B); also elsewhere on the board
/MachXO5/LED2: U1.R1 (PL37A); also elsewhere on the board
/MachXO5/LED3: U1.P7 (PL36B); also elsewhere on the board
/MachXO5/LED4: U1.H12 (PT37B); also elsewhere on the board
/MachXO5/LED5: U1.H11 (PT35B); also elsewhere on the board
/MachXO5/LED6: U1.G13 (PT51B); also elsewhere on the board
/MachXO5/LED7: U1.G12 (PT37A); also elsewhere on the board
/MachXO5/PL2A: J2.1, U1.B1 (PL2A)
/MachXO5/PL2B: J2.3, U1.C1 (PL2B)
/MachXO5/PL3A: J2.7, U1.D2 (PL3A)
/MachXO5/PL3B: J2.9, U1.D1 (PL3B)
/MachXO5/PL4A: J2.2, U1.E3 (PL4A)
/MachXO5/PL4B: J2.4, U1.E2 (PL4B)
/MachXO5/PL5A: J2.8, U1.E1 (PL5A)
/MachXO5/PL5B: J2.10, U1.F1 (PL5B)
/MachXO5/PT8A: J3.1, U1.C2 (PT8A)
/MachXO5/PT8B: J3.3, U1.B2 (PT8B)
/MachXO5/PT9A: J3.7, U1.A2 (PT9A)
/MachXO5/PT9B: J3.9, U1.A3 (PT9B)
/MachXO5/PT10A: J3.2, U1.D3 (PT10A)
/MachXO5/PT10B: J3.4, U1.C3 (PT10B)
/MachXO5/PT11A: J3.8, U1.B3 (PT11A)
/MachXO5/PT11B: J3.10, U1.A4 (PT11B)
/MachXO5/VCC_ADC: C9.2, C15.2, FB4.2, U1.W16 (VCCADC18)
/MachXO5/VCC_AUX: C6.2, C12.2, C18.2, C23.2, FB1.2, U1.E12 (VCCAUX), U1.J9 (VCCAUX), U1.L11 (VCCAUX), U1.[E12,J9,L11] (VCCAUX)
/MachXO5/VCC_AUXA: C7.2, C13.2, C19.2, FB2.2, U1.E9 (VCCAUXA), U1.J11 (VCCAUXA), U1.[E9,J11] (VCCAUXA)
/MachXO5/VCC_AUXH: C8.2, C14.2, C20.2, FB3.2, U1.P12 (VCCAUXH5), U1.R8 (VCCAUXH6)
/MachXO5/~BTN0: C32.2, R15.2, R16.1, U1.P3 (PL34A)
/MachXO5/~INIT: R9.1, U1.E13 (INITN); also elsewhere on the board
/MachXO5/~PROGRAM: R12.1, U1.F12 (PROGRAMN)
GND: C1.1, C2.1, C3.1, C4.1, C5.1, C6.1, C7.1, C8.1, C9.1, C10.1, C11.1, C12.1, C13.1, C14.1, C15.1, C16.1, C17.1, C18.1, C19.1, C20.1, C21.1, C22.1, C23.1, C24.1, C25.1, C26.1, C27.1, C28.1, C29.1, C30.1, C31.1, C32.1, C33.1, C34.1, C35.1, C36.1, C37.1, C38.1, C39.1, C40.1, C41.1, C42.1, C43.1, C44.1, C45.1, C47.1, C48.1, C50.1, C51.1, C52.1, C53.1, C54.1, C55.1, C75.1, C76.1, J2.5, J3.5, SW1.3, SW1.4, SW2.3, SW2.4, U1.A1 (VSS), U1.A20 (VSS), U1.D4 (VSS), U1.D7 (VSS), U1.D9 (VSS), U1.D12 (VSS), U1.D14 (VSS), U1.D17 (VSS), U1.F3 (VSS), U1.F18 (VSS), U1.H3 (VSS), U1.H18 (VSS), U1.J10 (VSS), U1.K10 (VSS), U1.L9 (VSS), U1.L10 (VSS), U1.L17 (VSS), U1.M4 (VSS), U1.M16 (VSS), U1.N5 (VSS), U1.R9 (VSS), U1.R12 (VSS), U1.R17 (VSS), U1.U4 (VSS), U1.U18 (VSS), U1.V7 (VSS), U1.V15 (VSS), U1.W3 (VSS), U1.W15 (ADC_REFP0), U1.W17 (VSSADC), U1.Y1 (VSS), U1.Y15 (ADC_REFP1), U1.Y16 (ADC_DP0), U1.Y17 (ADC_DN0), U1.Y18 (ADC_DP1), U1.Y19 (ADC_DN1), U1.Y20 (VSS), U1.[A1,A20,D4,D7,D9,D1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 (VSS), Y1.2 (GND); also elsewhere on the board
unnamed: C31.2, R12.2, R13.2, R14.1
unnamed: R14.2, SW1.1, SW1.2
unnamed: R16.2, SW2.1, SW2.2

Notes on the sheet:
BUTTONS

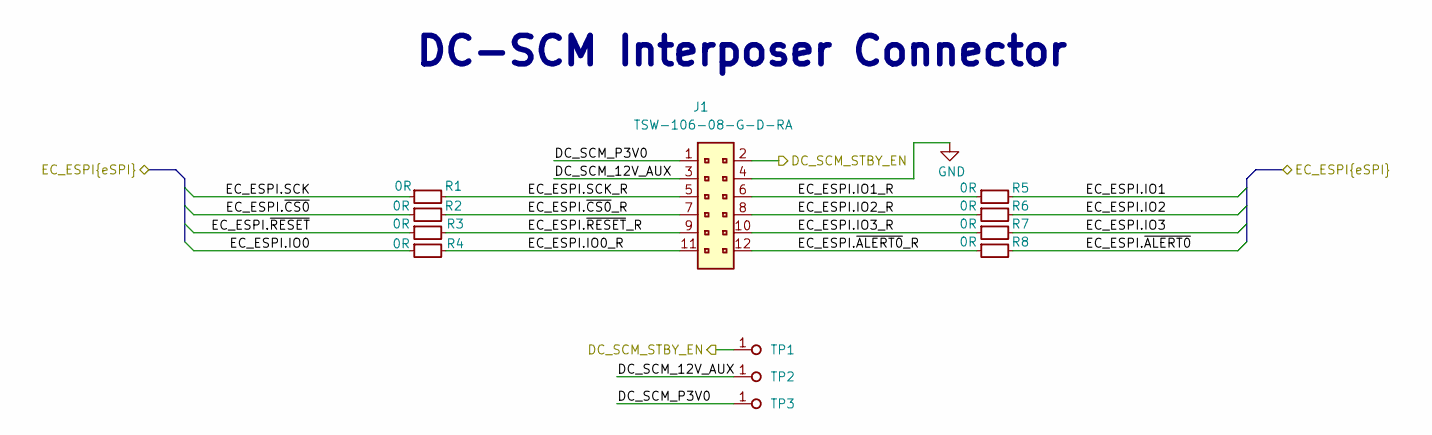
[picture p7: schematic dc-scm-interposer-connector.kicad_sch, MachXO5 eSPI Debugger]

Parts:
J1: PinHeader_2x6_P2.54mm_Drill1.1mm_Horizontal; PinHeader_2x6_P2.54mm_Drill1.1mm_Horizontal_ALT; MPN TSW-106-08-G-D-RA
R1, R2, R3, R4, R5, R6, R7, R8: R_0R_0402; R_0402_1005Metric; MPN ERJ2GE0R00X
TP1, TP2, TP3: TP_1mm_SMD; TP_SMD_1mm

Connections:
/DC-SCM Interposer connector/DC_SCM_12V_AUX: J1.3, TP2.1 (1_1)
/DC-SCM Interposer connector/DC_SCM_P3V0: J1.1, TP3.1 (1_1)
/DC-SCM Interposer connector/DC_SCM_STBY_EN: J1.2, TP1.1 (1_1); also elsewhere on the board
/DC-SCM Interposer connector/EC_ESPI.IO0: R4.1; also elsewhere on the board
/DC-SCM Interposer connector/EC_ESPI.IO0_R: J1.11, R4.2
/DC-SCM Interposer connector/EC_ESPI.IO1: R5.2; also elsewhere on the board
/DC-SCM Interposer connector/EC_ESPI.IO1_R: J1.6, R5.1
/DC-SCM Interposer connector/EC_ESPI.IO2: R6.2; also elsewhere on the board
/DC-SCM Interposer connector/EC_ESPI.IO2_R: J1.8, R6.1
/DC-SCM Interposer connector/EC_ESPI.IO3: R7.2; also elsewhere on the board
/DC-SCM Interposer connector/EC_ESPI.IO3_R: J1.10, R7.1
/DC-SCM Interposer connector/EC_ESPI.SCK: R1.1; also elsewhere on the board
/DC-SCM Interposer connector/EC_ESPI.SCK_R: J1.5, R1.2
/DC-SCM Interposer connector/EC_ESPI.~ALERT0: R8.2; also elsewhere on the board
/DC-SCM Interposer connector/EC_ESPI.~ALERT0_R: J1.12, R8.1
/DC-SCM Interposer connector/EC_ESPI.~CS0: R2.1; also elsewhere on the board
/DC-SCM Interposer connector/EC_ESPI.~CS0_R: J1.7, R2.2
/DC-SCM Interposer connector/EC_ESPI.~RESET: R3.1; also elsewhere on the board
/DC-SCM Interposer connector/EC_ESPI.~RESET_R: J1.9, R3.2
GND: J1.4; also elsewhere on the board

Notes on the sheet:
DC-SCM Interposer Connector

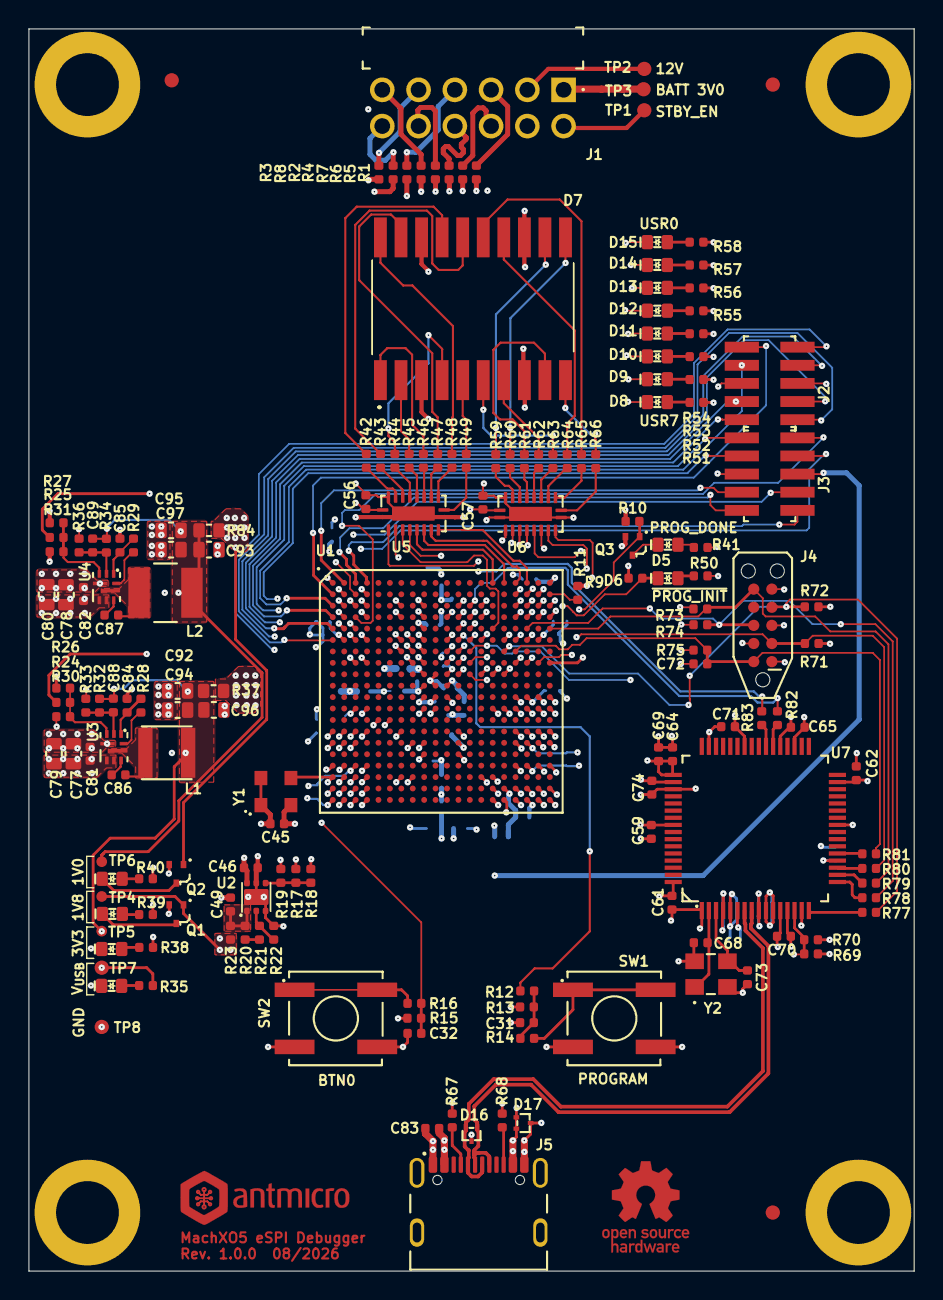
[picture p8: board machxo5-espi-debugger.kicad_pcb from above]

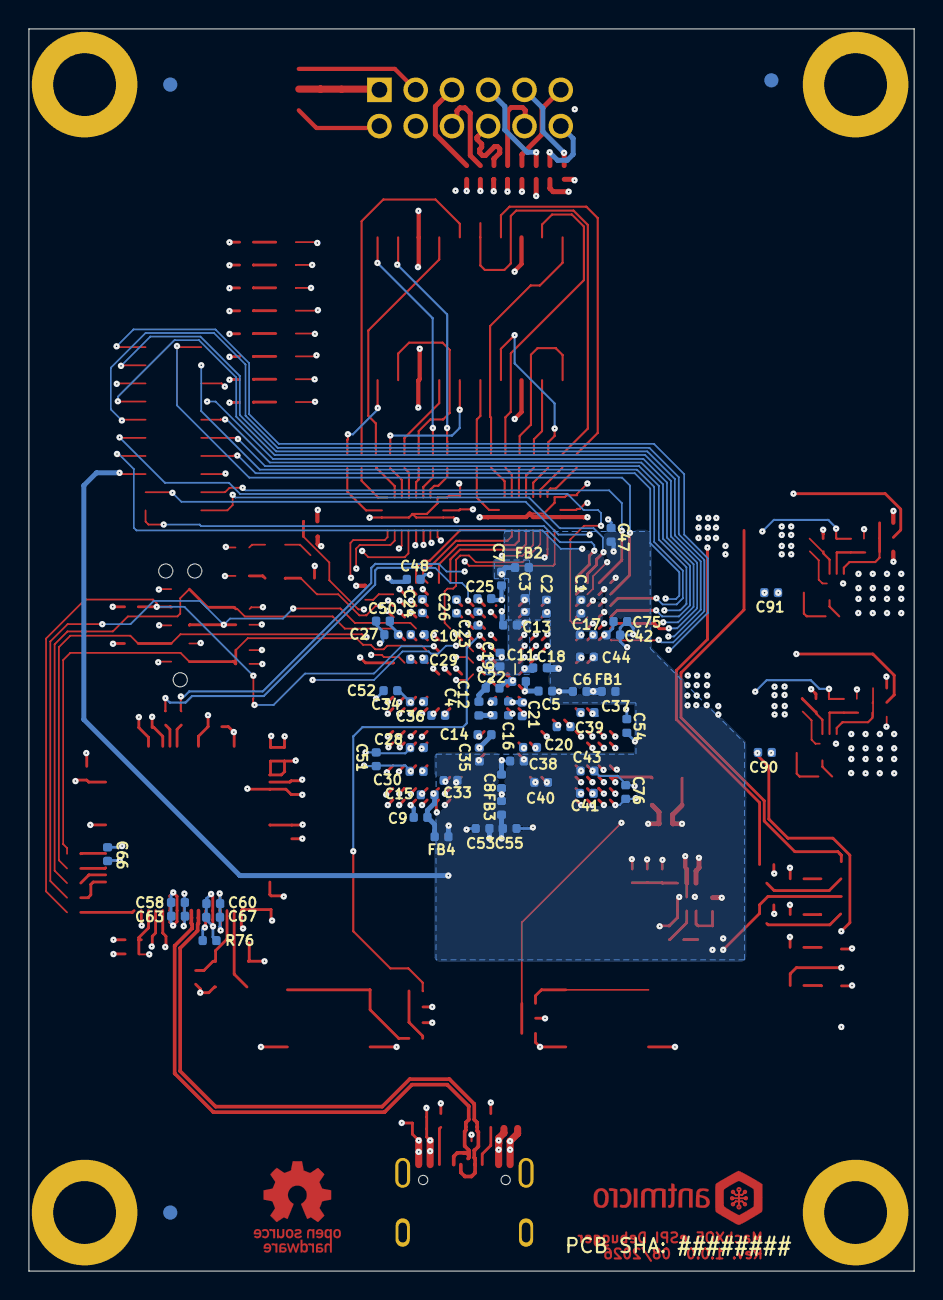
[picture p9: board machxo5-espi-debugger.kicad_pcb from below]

Board: 6 copper layers, 62.0 x 87.0 mm, 243 parts (71 on the bottom side), 167 nets.

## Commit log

2026-08-26 [#103910] Init KiCad Project
    [connectors.kicad_sch, dc-scm-interposer-connector.kicad_sch, flash.kicad_sch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]
2026-08-26 [#103910] Update power section
    [dc-scm-interposer-connector.kicad_sch, machxo5-espi-debugger.kicad_sch, machxo5.kicad_sch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]
2026-08-26 [#103910] machxo5: update LFMXO5-25-7BBG400C symbol
    [machxo5.kicad_sch]
2026-08-26 [#103910] machxo5: connect eSPI
    [machxo5.kicad_sch]
2026-08-26 [#103910] machxo5: connect JTAG, UART and LEDs
    [machxo5.kicad_sch]
2026-08-26 [#103910] machxo5: connect 3.3V to Bank2
    [machxo5.kicad_sch]
2026-08-26 [#103910] machxo5: connect 125MHz clock
    [machxo5.kicad_sch]
2026-08-26 [#103910] machxo5: connect power to FPGA core
    [machxo5.kicad_sch]
2026-08-26 [#103910] machxo5: connect 7-segment high digit
    [machxo5.kicad_sch]
2026-08-27 [#103910] Complete schematics
    [machxo5-espi-debugger.kicad_sch, machxo5.kicad_sch, port80-leds.kicad_sch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]
2026-08-27 [#103910] Annotate schematics & Clean ERC
    [dc-scm-interposer-connector.kicad_sch, machxo5.kicad_sch, port80-leds.kicad_sch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]
2026-08-27 [#103910] Sch: remove testpoints on SPI
    [dc-scm-interposer-connector.kicad_sch]
2026-08-27 [#103953] Prepare placement
    [machxo5-espi-debugger.kicad_pcb]
2026-08-27 [#103953] Initial eSPI routing
    [dc-scm-interposer-connector.kicad_sch, machxo5-espi-debugger.kicad_pcb]
2026-08-27 [#103953] sch/pcb: re-annotate components
    [dc-scm-interposer-connector.kicad_sch, machxo5-espi-debugger.kicad_pcb, machxo5-espi-debugger.kicad_sch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]
2026-08-27 [#103953] pcb: partial layout of the DC-DC section
    [machxo5-espi-debugger.kicad_pcb]
2026-08-27 [#103953] sch: machxo5: move R11 further from the JTAG_EN label
    [machxo5.kicad_sch]
2026-08-27 [#103953] sch: machxo5: unify decoupling label placement
    [machxo5.kicad_sch]
2026-08-27 [#103953] sch: machxo5: fix crossing text on J2/J3
    [machxo5.kicad_sch]
2026-08-27 [#103953] sch: usb_debug: add missing labels
    [usb_debug.kicad_sch]
2026-08-27 [#103953] sch: power: move status leds outside of the project table
    [power.kicad_sch]
2026-08-27 [#103953] pcb: import new labels from sch
    [machxo5-espi-debugger.kicad_pcb]
2026-08-28 [#103953] Continue routing
    [machxo5-espi-debugger.kicad_pcb]
2026-08-28 [#103953] Complete routing
    [machxo5-espi-debugger.kicad_pcb]
2026-08-28 [#103953] Sch: Update DCDC
    [machxo5-espi-debugger.kicad_sch, machxo5.kicad_sch, power.kicad_sch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]
2026-08-28 [#103953] PCB: Update DCDC
    [machxo5-espi-debugger.kicad_pcb, power.kicad_sch]
2026-08-28 [#103953] PCB: Update FPGA fanout
    [machxo5-espi-debugger.kicad_pcb]
2026-08-28 [#103953] Finish PCB layout
    [dc-scm-interposer-connector.kicad_sch, machxo5-espi-debugger.kicad_pcb, machxo5-espi-debugger.kicad_sch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]
2026-08-28 [#103953] sch: power: align text to not intersect symbols
    [power.kicad_sch]
2026-08-28 [#103953] sch: usb: set pin functions for tag-connect
    [usb_debug.kicad_sch]
2026-08-28 [#103953] sch: machxo5: move buttons to not intersect the table
    [machxo5.kicad_sch]
2026-08-29 [#103953] pcb: update copper to hole clearance
2026-08-29 [#103953] pcb: resolve DRC
    [machxo5-espi-debugger.kicad_pcb]
2026-08-29 [#103953] pcb: eSPI length tunning
    [machxo5-espi-debugger.kicad_pcb]
2026-08-29 [#103953] pro: bump date
    [dc-scm-interposer-connector.kicad_sch, machxo5-espi-debugger.kicad_pcb, machxo5-espi-debugger.kicad_sch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]
2026-09-09 Add board dimensions
    [machxo5-espi-debugger.kicad_pcb]
2026-09-09 Add initial README and board render
2026-09-15 [#105108] Flip spacers for bottom layer
    [machxo5-espi-debugger.kicad_pcb]
2026-09-15 [#105108] Update README image with flipped spacers

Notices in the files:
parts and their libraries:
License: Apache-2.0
